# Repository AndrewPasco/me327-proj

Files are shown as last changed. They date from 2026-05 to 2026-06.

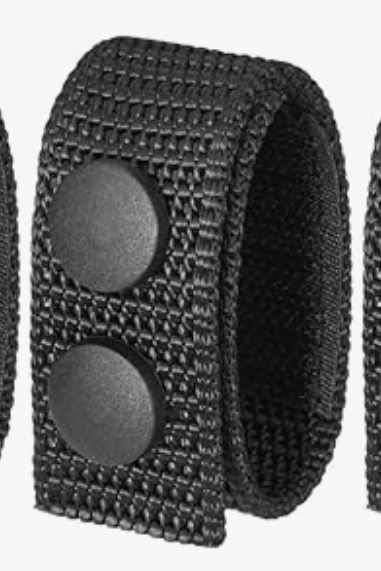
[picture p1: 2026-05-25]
media/belt-keeper.png

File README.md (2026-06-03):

# ME327 Haptic Belt: Covert Early Warning Communication System

> **ME327: Design and Control of Haptic Systems — Team 14**  
> Joseph Heimerl · Andrew Pasco · Ashlynn Sweet · Brody Todd

A wearable haptic belt that translates aerial threat detections (e.g., UAV positions) into real-time directional tactile cues. Eight coin-style ERM vibration motors spaced around the waist give the operator a passive, silent, always-on awareness of threats in their environment.

---

## How It Works

1. A **host computer** (running a threat-detection or simulation pipeline) detects a threat and encodes its position as `(x, y, z)` coordinates in a local frame.
2. The host sends a BLE packet to the belt controller (Particle Argon).
3. The **BNO085 IMU** continuously provides the operator's orientation as a quaternion.
4. The firmware computes the **relative bearing** from the operator to the threat, selects the nearest motor(s), and drives them at an intensity inversely proportional to threat range.
5. The belt simultaneously streams the current orientation quaternion back to the host for visualization.

As the operator turns, the vibration pattern rotates with them — always pointing toward the threat in the operator's frame.

---

## Repository Structure

```
me327-proj/
├── Analysis/                          # Vibration analysis
│   └── Analysis.m                     # MATLAB 2-DOF housing vibration model
├── CAD/                               # 3D-printed housing and belt buckle STL files
├── belt_controller/                   # Earlier prototype firmware (reference)
├── controllerTest/                    # Firmware + host BLE utilities
│   ├── controllerTest/                # Particle Workbench project
│   │   ├── src/                       # All firmware source
│   │   │   ├── controllerTest.cpp     # Entry point (setup / loop)
│   │   │   ├── HapticBelt.h/.cpp      # Top-level orchestrator
│   │   │   ├── BeltBLE.h/.cpp         # BLE peripheral (Rx threats / Tx orientation)
│   │   │   ├── BeltIMU.h/.cpp         # IMU interface + quaternion math
│   │   │   ├── ThreatTracker.h/.cpp   # Threat state machine (parse + store)
│   │   │   ├── HapticSignature.h      # Temporal vibration patterns per threat
│   │   │   └── MotorDriver.h/.cpp     # PWM abstraction for 8 ERM motors
│   │   ├── lib/                       # Vendored libraries
│   │   │   ├── Adafruit_BNO08x_Sahagun/
│   │   │   ├── Adafruit_BusIO_Sahagun/
│   │   │   └── Adafruit_Unified_Sensor_Sahagun/
│   │   └── project.properties         # Particle project config + dependencies
│   ├── bleakListener.py               # Host: receive orientation from belt (debug)
│   ├── bleakScanAndListen             # Host: scan + connect by device name
│   ├── bleakScanner                   # Host: passive BLE scanner
│   └── serialListener.py              # Host: USB Serial monitor
├── docs/                              # Design notes and project documentation checkpoints
├── media/                             # Visual assets for the project documentation
├── v_env/                             # Host-side GUI & threat simulation scripts
│   ├── brody_sim_main.py              # Main demo simulation (waves + spiral threats)
│   ├── gui_ashlynn_sim.py             # Game-mode simulation (4 escalating waves)
│   ├── gui_update_on_event.py         # Interactive debug / intro GUI (click-to-place)
│   ├── gui_drag_and_drop.py           # Drag-and-drop threat placement
│   ├── gui_single.py                  # Single-threat GUI
│   ├── gui_mult.py                    # Multi-threat GUI
│   ├── gui_varforce.py                # Variable-force multi-threat GUI
│   ├── gui_update_continously.py      # Continuous-update visualization
│   ├── update_on_event_brody_simulation.py      # BLE simulation + mouse test
│   ├── update_on_event_brody_simulation_TEST.py # Test variant of above
│   ├── pyproject.toml                 # Python project configuration
│   └── uv.lock                        # Lockfile for Python dependencies
├── architecture.md                    # Detailed design and architecture document
├── LICENSE                            # MIT License
└── README.md                          # This file
```

---

## Hardware

| Component | Part | Notes |
| :--- | :--- | :--- |
| Microcontroller | Particle Argon (nRF52840) | BLE, I2C, 12 PWM pins |
| IMU | BNO085 (I2C) | Game Rotation Vector report @ ~100 Hz |
| Motor Drivers | DRV8833 ×4 | 2 motors per driver, PWM control |
| Actuators | 8× coin ERM vibration motors | Equally spaced around waist |
| Structure | Elastic belt + 3D-printed clamshell housings | Rigid skin contact |

### Pin Mapping (Particle Argon)

| Resource | Pins |
| :--- | :--- |
| IMU (I2C) | SDA / SCL (default bus) |
| Motor 0 (forward) | D5 |
| Motor 1 | A5 |
| Motor 2 | A4 |
| Motor 3 | A2 |
| Motor 4 | A1 |
| Motor 5 | D6 |
| Motor 6 | D8 |
| Motor 7 | D4 |
| Status LED | D7 (onboard) |

---

## Firmware

### Building & Flashing

The firmware is a [Particle Workbench](https://docs.particle.io/tools/developer-tools/workbench/) project.

1. Open `controllerTest/controllerTest/` in VS Code with the Particle Workbench extension installed.
2. Select your target device (Argon) and Device OS version.
3. Run **Particle: Flash application (local)** or use the Particle CLI:

```bash
particle flash --usb controllerTest
```

### Software Modules

See [`architecture.md`](architecture.md) for the full design document. In brief:

| Module | Class | Purpose |
|:---|:---|:---|
| Orchestrator | `HapticBelt` | Ties all subsystems together; owns the main `loop()` |
| BLE | `BeltBLE` | GATT peripheral; Rx threat packets, Tx orientation quaternion |
| IMU | `BeltIMU` | BNO085 driver; quaternion re-orientation, reset recovery |
| Threat State | `ThreatTracker` | Parses BLE packets; maintains up to 10 active threats |
| Haptic Signatures | `HapticSignature` | Temporal vibration patterns (on/off timing) per threat for tactile differentiation |
| Motors | `MotorDriver` | PWM abstraction for 8 ERMs at 500 Hz |

### BLE Protocol

The belt advertises as **`"Argon Test"`** over BLE with service UUID `62c3cf89-247b-4c0f-a70d-651080844609`.

**Host → Belt (Rx characteristic `...844609`)**

Semicolon-separated threat packets, UTF-8 encoded:
```
"<id>,<x>,<y>,<z>[;<id>,<x>,<y>,<z>;...]"
```
- `id`: integer threat identifier (0–9; each slot has a unique haptic signature)
- `x`, `y`: position in the host's local frame (meters or arbitrary units; `+x` = right, `+y` = forward)
- `z`: depth / altitude — set to `-1` to **remove** a threat

**Belt → Host (Tx characteristic `...844608`)**

Orientation quaternion, sent as a comma-separated string each loop:
```
"<w>,<x>,<y>,<z>"
```

---

## Host-Side Python Tools

### BLE Debug Utilities

Located in `controllerTest/`. Dependencies managed with `uv`.

```bash
# Install dependencies
cd controllerTest
uv add bleak

# Listen for orientation packets from the belt
uv run bleakListener.py

# Scan for the belt and listen
uv run bleakScanAndListen

# USB Serial monitor (no BLE required)
uv run serialListener.py
```

> **Device MAC address** is printed over USB Serial at boot:  
> `BLE MAC: XX:XX:XX:XX:XX:XX`  
> Update `DEVICE_MAC` in the Python scripts accordingly.

### Simulation & GUI

Located in `v_env/`. Requires `pygame` and `bleak`.

| Script | Purpose |
| :--- | :--- |
| `brody_sim_main.py` | **Main demo simulation.** Spiral threats approach across escalating waves; merges Ashlynn's wave logic with Brody's UI. Used during the live demo. |
| `gui_update_on_event.py` | **Interactive debug / intro tool.** Click to place threats, drag to reposition, right-click to remove. Sector wheel visualization shows motor mapping. Good for introducing a user to the system. |
| `gui_ashlynn_sim.py` | Game-mode simulation with 4 escalating waves and lock-on neutralization mechanic. |
| `gui_drag_and_drop.py` | Simple drag-and-drop threat placement GUI. |
| `gui_single.py` | Single-threat GUI with BLE. |
| `gui_mult.py` | Multi-threat GUI with BLE. |
| `gui_varforce.py` | Multi-threat with variable force GUI. |
| `gui_update_continously.py` | Continuous-update threat visualization with sector wheel. |

All simulation scripts connect to the belt automatically by scanning for a device named `"Argon"`.

**Controls (simulation scripts):**
- `SPACE` — start / restart simulation
- `← →` arrow keys — rotate heading manually (when BLE is not connected)

---

## IMU Orientation Notes

The BNO085 reports orientation relative to its default flat-mount frame. The firmware corrects for the physical mounting orientation of the board on the belt via a configurable initial quaternion passed to `BeltIMU::setup()`:

```cpp
// HapticBelt.cpp — adjust to match your board mounting angle
Quat initialOrientation{sqrt(2)/2, 0, sqrt(2)/2, 0};
IMUHandler.setup(initialOrientation);
```

To find the right quaternion for a new mounting orientation:
1. Orient the belt as you want "forward" to be.
2. Read the raw quaternion over Serial.
3. Pass that quaternion as `initialOrientation`.

The IMU module also handles sensor resets transparently: it computes a continuity-preserving offset quaternion so the heading does not jump when the BNO085 resets mid-session.

---

## Haptic Rendering

Motor index 0 corresponds to "forward" (front of the belt). Motors are numbered 0–7 clockwise when viewed from above.

For each active threat:
1. Compute target azimuth: `-(atan2(y, x) × 180/π − 90°)` — converts from standard math to compass convention (0° = forward, clockwise positive)
2. Subtract current yaw to get relative bearing, normalized to (−180°, +180°]
3. Map bearing to nearest motor index (45° sectors)
4. Scale intensity: `intensity = clamp(1 − range/400, 0.1, 1.0)`

Each threat slot (0–9) is assigned a unique **haptic signature** — a temporal on/off vibration pattern defined in `HapticSignature`. This allows the operator to distinguish between multiple simultaneous threats by feel. The motor only fires when the threat's signature is in its "active" phase.

---

## Analysis & Simulation

We also model the mechanical dynamics of the belt for design optimization:

**`Analysis/Analysis.m`** (MATLAB) — 2-DOF mass-spring-damper model comparing vibration response of an unconstrained belt vs. a belt worn on a person. Models ERM forcing and housing dynamics.

---

## License

MIT License
ME327 Academic Project, Stanford University, Spring 2026.

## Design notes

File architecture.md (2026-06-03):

## ME327 Haptic Belt — Requirements and Code Architecture

This document describes the requirements for the haptic belt firmware and the implemented code architecture.

---

### Requirements

1. Receive incoming local-frame threat detections (as if detected by a device worn by the operator) via BLE from the host computer.
   - Determine the relative threat vector. Based on the relative threat vector, determine which motor(s) should be activated and their associated duty cycles.
   - Update the relative threat vector as the operator moves / yaws.
2. Process incoming data from the BNO085 IMU.
   - Calibrate belt mounting orientation at startup (configurable initial quaternion).
   - Maintain continuous orientation estimate; recover gracefully from IMU resets.
3. Stream the current orientation quaternion back to the host computer for rendering / visualization.
4. Manage PWM signals to 8 ERM vibration motors based on detected threats.

---

### Relevant System Details

**Microcontroller:** Particle Argon (Nordic Semiconductor nRF52840 SoC)
- ARM Cortex-M4F @ 64 MHz, 1 MB flash, 256 KB RAM
- Bluetooth LE central and peripheral support
- 20 mixed-signal GPIO (6× Analog, 8× PWM), UART, I2C, SPI
- Hardware FPU; DSP instructions; AES encryption accelerator
- 12 PWM-compatible pins, organized in three groups of four (same frequency per group; independent duty cycles)

**IMU:** BNO085 (I2C, via Adafruit_BNO08x library, Sahagun fork)
- Reports used: `SH2_GAME_ROTATION_VECTOR` (absolute orientation quaternion)
- Quaternion re-orientation applied at startup; offset correction applied after any sensor reset

**Motor Drivers:** DRV8833 ×4, controlled via PWM

---

### Implemented Architecture

#### 1. Coordinate Frames

| Frame | Description |
| :--- | :--- |
| **Global Frame (G)** | Fixed to the world. Threat positions are expressed here (x, y, z coordinates received from host). |
| **Body Frame (B)** | The current orientation of the belt/user. |
| **Initial/Reference Orientation** | A configurable quaternion passed to `BeltIMU::setup()` representing where the IMU is considered "forward" relative to its flat-mount default. Currently set to `{√2/2, 0, √2/2, 0}` to account for board mounting angle. |

#### 2. Class Hierarchy & Responsibilities

```
HapticBelt          (top-level orchestrator)
├── BeltBLE         (BLE peripheral: Rx threat data, Tx orientation)
├── BeltIMU         (I2C IMU interface: quaternion + heading)
├── ThreatTracker   (parses BLE packets, maintains threat state)
│   └── HapticSignature  (temporal vibration pattern per threat)
└── MotorDriver     (PWM abstraction for 8 ERM motors)
```

| Class | File(s) | Responsibility |
| :--- | :--- | :--- |
| **HapticBelt** | `HapticBelt.h/.cpp` | Top-level orchestrator. Owns all subsystems. Calls `setup()` and `loop()`. Pulls quaternion from `BeltIMU`, converts to yaw, queries active threats from `ThreatTracker`, maps threats to motors, and transmits orientation back over BLE via `BeltBLE`. |
| **BeltBLE** | `BeltBLE.h/.cpp` | Manages the BLE peripheral. Registers custom GATT service with Rx (write-without-response) and Tx (notify) characteristics. Passes a callback+context to the Rx characteristic on setup. Provides `transmit_orientation(w,x,y,z)` to broadcast the current quaternion. |
| **BeltIMU** | `BeltIMU.h/.cpp` | Interfaces with the BNO085 via I2C. Applies an initial re-orientation quaternion at startup. Handles IMU resets by computing a continuity-preserving offset quaternion. Exposes `get_quaternion()` (relative to initial orientation) and `get_heading()` (yaw in degrees). |
| **ThreatTracker** | `ThreatTracker.h/.cpp` | Holds a fixed-size array of up to 10 `Threat` structs. Provides a static `rx_callback` (passed to `BeltBLE::setup`) that stores incoming BLE bytes behind a `Mutex`. `update()` parses the buffered string and adds/updates/removes threats. `getActiveThreats()` returns pointers to currently active threats. Each threat slot is pre-assigned a unique `HapticSignature` at construction. |
| **HapticSignature** | `HapticSignature.h` | Defines a temporal on/off vibration pattern via an array of switch times (milliseconds). `is_active()` returns whether the motor should fire at the current time, cycling through the pattern. A zero-length signature is always on. Up to 10 entries per pattern (`MAX_SIGNATURE_LENGTH = 10`). |
| **MotorDriver** | `MotorDriver.h/.cpp` | Abstracts PWM control for 8 motors at 500 Hz. Maps motor index 0–7 to Argon pins `{D5, A5, A4, A2, A1, D6, D8, D4}`. `triggerMotor(index, intensity)` writes a 0–255 PWM value; `stopAllMotors()` zeroes all channels. |

#### 3. Key Data Structures

```cpp
// BeltIMU.h
struct Quat {
    float w, x, y, z;
};
// Utility functions (free functions in BeltIMU.cpp):
Quat Qmultiply(const Quat& a, const Quat& b); // Hamilton product + normalize
Quat Qconj(const Quat& q);                     // Quaternion conjugate
Quat Qnormalize(Quat q);                        // Unit normalization
void printQuat(Quat q);                          // Serial debug print

// HapticSignature.h
class HapticSignature {
    unsigned long switchTimes[MAX_SIGNATURE_LENGTH]; // on/off durations (ms)
    size_t length;                                   // 0 = always on
    bool is_active();  // returns current on/off state, cycling through pattern
};

// ThreatTracker.h
struct Threat {
    int   id     = -1;
    bool  active = false;
    float coords[3] = {0, 0, 0};  // x, y, z in host coordinate frame
    HapticSignature signature;     // unique temporal vibration pattern
};
```

#### 4. Data Flow (Main Loop)

```
setup():
  BeltBLE::setup(ThreatTracker::rx_callback, &ThreatTrack)
    └─ registers Rx/Tx GATT characteristics; begins BLE advertising

  BeltIMU::setup({√2/2, 0, √2/2, 0})
    └─ begin_I2C(), enable SH2_GAME_ROTATION_VECTOR report, store initQ

  MotorDriver::setup()
    └─ configure 8 PWM pins @ 500 Hz, zero all outputs

loop() [runs continuously]:
  1. BeltIMU::check_connection()
        └─ reconnects if needed; computes offset quaternion after any IMU reset

  2. BeltIMU::get_quaternion()
        └─ reads SH2 rotation vector → applies re-orientation (Qmultiply(raw, Qconj(initQ)))
           → applies continuity offset → returns finalQuat

  3. Convert quaternion → yaw (degrees) via standard Euler decomposition:
        yaw = -atan2(2(w·z + x·y), 1 − 2(y² + z²)) × 180/π   // negated for compass convention

  4. ThreatTracker::update()
        └─ safely copies buffered byteString (Mutex-protected)
           → parses semicolon-separated "id,x,y,z" tokens
           → z == -1 ⟹ deactivate; otherwise add/update threat

  5. HapticBelt::renderHaptics(yaw)
        a. getActiveThreats() → list of active Threat*
        b. For each threat:
             targetAzimuth = -(atan2(y, x) × 180/π − 90°)  // compass convention
             error = targetAzimuth − yaw                     // relative bearing
             error normalized to (−180, +180]
             motorIndex = round(normalizeAngle(error) / 45°) mod 8
             range = √(x² + y²)
             intensity = clamp(1 − range/400, 0.1, 1.0)
             if threat.signature.is_active():                // haptic signature gating
                 MotorDriver::triggerMotor(motorIndex, intensity)

  6. BeltBLE::transmit_orientation(w, x, y, z)
        └─ formats as "w,x,y,z" string → Tx NOTIFY characteristic
```

#### 5. BLE Protocol

| Direction | UUID | Format | Description |
| :--- | :--- | :--- | :--- |
| Host → Belt (Rx) | `...844609` | `"id,x,y,z[;id,x,y,z...]"` | Semicolon-separated threat packets. `z == -1` signals threat removal. |
| Belt → Host (Tx) | `...844608` | `"w,x,y,z"` | Current orientation quaternion, 2 decimal places, sent each loop. |

#### 6. Hardware Pin Mapping (Particle Argon)

| Resource | Pin(s) | Notes |
| :--- | :--- | :--- |
| **IMU (I2C)** | SDA / SCL (default I2C bus) | BNO085 via `Adafruit_BNO08x` |
| **Motor 0 (forward)** | D5 | DRV8833 PWM input |
| **Motor 1** | A5 | DRV8833 PWM input |
| **Motor 2** | A4 | DRV8833 PWM input |
| **Motor 3** | A2 | DRV8833 PWM input |
| **Motor 4** | A1 | DRV8833 PWM input |
| **Motor 5** | D6 | DRV8833 PWM input |
| **Motor 6** | D8 | DRV8833 PWM input |
| **Motor 7** | D4 | DRV8833 PWM input |
| **Status LED** | D7 (onboard) | Blink each loop iteration |
| **PWM Frequency** | 500 Hz | Set via `analogWrite(pin, 0, 500)` in `MotorDriver::setup()` |

---

### Third-Party Dependencies

| Library | Version | Purpose |
| :--- | :--- | :--- |
| `Adafruit_BNO08x_Sahagun` | 1.2.6 | BNO085 I2C driver (forked for Particle compatibility) |
| `Adafruit_BusIO_Sahagun` | — | I2C/SPI bus abstraction (transitive dep) |
| `Adafruit_Unified_Sensor_Sahagun` | — | Unified sensor abstraction (transitive dep) |

Dependencies are declared in `controllerTest/project.properties` and bundled under `controllerTest/lib/`.

---

### Host-Side Tooling (Python)

#### BLE Debug Utilities

Located in `controllerTest/`:

| Script | Purpose |
| :--- | :--- |
| `bleakListener.py` | Connects to the Argon by MAC address, subscribes to the Tx characteristic (orientation), and prints received packets to stdout. Development/debug tool. |
| `bleakScanAndListen` | Scans for the Argon by device name (`"Argon Test"`) before connecting. |
| `bleakScanner` | Passive BLE scanner utility. |
| `serialListener.py` | Reads USB Serial output from the Argon for local debug without BLE. |

Dependencies managed with `uv`. Run with `uv run <script>` after adding `bleak` via `uv add bleak`.

#### Simulation & GUI

Located in `v_env/`. Requires `pygame` and `bleak`.

| Script | Purpose |
| :--- | :--- |
| `brody_sim_main.py` | **Main demo simulation.** Spiral threats approach across escalating waves; merges Ashlynn's wave logic with Brody's UI. Used during the live demo. |
| `gui_update_on_event.py` | **Interactive debug / intro tool.** Click to place threats, drag to reposition, right-click to remove. Sector wheel visualization shows motor mapping in real time. |
| `gui_ashlynn_sim.py` | Game-mode simulation with 4 escalating waves and lock-on neutralization mechanic. |
| `gui_drag_and_drop.py` | Simple drag-and-drop threat placement GUI. |
| `gui_single.py` | Single-threat GUI with BLE. |
| `gui_mult.py` | Multi-threat GUI with BLE. |
| `gui_varforce.py` | Multi-threat with variable force GUI. |
| `gui_update_continously.py` | Continuous-update threat visualization with sector wheel. |

All simulation scripts auto-connect to the belt by scanning for a device named `"Argon"`. Controls: `SPACE` to start/restart, `← →` arrow keys to rotate heading manually (when BLE is not connected).

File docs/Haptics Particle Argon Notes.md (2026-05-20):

# BLE stuff
look at ppcp for improving transfer rates

Making services:
```cpp
// PROTOTYPE 
BleUuid(const String& uuid); 
BleUuid(const char* uuid);
// EXAMPLE 
BleUuid myCustomService("240d5183-819a-4627-9ca9-1aa24df29f18");
```

Giving Services characteristics
- no separate class for the characteristic, a characteristic is determined buy a uuid as well
```cpp
// global variables
BleUuid myCustomCharacteristicUuid("240d5183-819a-4627-9ca9-1aa24df29f18");

//example implementation
BleCharacteristic customChar("temp",
 							BleCharacteristicProperty::NOTIFY, //see below
 							myCustomCharacteristicUuid, 
 							myCustomService);

// then I think you need to add the characteristic
// in setup
setup() {
	BLE.addCharacteristic(customChar);
}
```

Appending services to the advertisement:
```cpp
// in setup:
BleAdvertisingData advData;
advData.appendServiceUUID(myCustomService);

BLE.setDeviceName("Argon Test");
BLE.advertise();
```

Different Characteristic Properties:
> [!info]+ BLE Characteristic Properties:
> - `BleCharacteristicProperty::BROADCAST` (0x01) The value can be broadcast.
>- `BleCharacteristicProperty::READ` (0x02) The value can be read.
> - `BleCharacteristicProperty::WRITE_WO_RSP` (0x04) The value can be written without acknowledgement. For example, the UART peripheral example uses this characteristic properly to receive UART data from the central device.
> - `BleCharacteristicProperty::WRITE` (0x08) The value can be written to the peripheral from the central device.
> - `BleCharacteristicProperty::NOTIFY` (0x10) The value is published by the peripheral without acknowledgement. This is the standard way peripherals periodically publish data.
> - `BleCharacteristicProperty::INDICATE` (0x20) The value can be indicated, basically publish with acknowledgement.
> - `BleCharacteristicProperty::AUTH_SIGN_WRITES` (0x40) The value supports signed writes. This is operation not supported.
> - `BleCharacteristicProperty::EXTENDED_PROP` (0x80) The value supports extended properties. This operation is not supported.

characteristics can have one or more values

How to actually do stuff with characteristics:
BLE characteristic w/ data recieved:

```cpp
// Global variable 
BleCharacteristic(	const char* desc, 
					BleCharacteristicProperty properties, 
					BleUuid charUuid, 
					BleUuid svcUuid, 
					BleOnDataReceivedCallback callback = nullptr, 
					void* context = nullptr) // context is extra info sent to 
											// callback (typically "this" if an 
											// object)

BleCharacteristic rxCharacteristic("rx",
 								  	BleCharacteristicProperty::WRITE_WO_RSP,
 								  	rxUuid, 
 								  	serviceUuid, 
 								  	onDataReceived, 
 								  	NULL);
 								  	
// The onDataRecieved is a callback function:
void onDataReceived(const uint8_t* data, 
					size_t len, 
					const BlePeerDevice& peer, 
					void* context)

// in setup, need to register characteristic (if a peripheral)
setup() {
	BLE.addCharacteristic(customChar);
	
	// can also tie the callback here
	myCharacteristic.onDataReceived(onDataReceived, NULL);
}
```

The `onDataReceived()` handler is run from the BLE thread. You should avoid lengthy or blocking operations since it will affect other BLE processing. Additionally, the BLE thread has a smaller stack than the main application (loop) thread, so you avoid functions that require a large amount of stack space. To prevent these issues, you should set a flag in the data received handler and perform lengthy or stack-intensive operations from the `loop()` instead. For example, you should not call `Particle.publish()`, `WiFi.clearCredentials()`, and many other functions directly from the onDataReceived handler.

To write data to a characteristic:
```cpp
// PROTOTYPE template
<typename T> 
ssize_t setValue(T val) const; 
// EXAMPLE 
uint16_t value = 0x1234; 
characteristic.setValue(value);
```
this apparently works with arbitrary data types including structs somehow I will have to test how that works

Because the onDataReceived is run on another thread, might have to do thread safety stuff
Log.info() is thread safe, serial is not

need to use a recursive mutex if one thread will be locking 

mutex example
```cpp
// globally
Mutex coordsMutex;

// in a funciton
WITH_LOCK(coordsMutex) {  
	localX = x;  
	localY = y;  
	localZ = z;  
}
```

## useful data transmission functions:
sscanf "string scan formatted"
parses formatted data from c string
<span style="color:rgb(192, 0, 0)">note c strings must end in a 0 byte</span> `'\0'`

address operator:
sscanf needs pointers to variables so it can write results.  
  
Correct:  
&x  
  
Incorrect:  
x
```cpp
int sscanf(const char* str, const char* format, ...); //returns number of successfully matched values 

char text[] = "1.23,4.56,7.89";

float x,y,z;
int matched = sscanf(  
	text,  
	"%f,%f,%f",  
	&x,  
	&y,  
	&z  
);
```

note:
uint8_t is exactly 1 byte of memory (8 bits per byte)
note the data arg for callback is: `const uint8_t* data`
- stores an array of bytes essentially

```cpp
void onDataReceived(const uint8_t* data, 
					size_t len, 
					const BlePeerDevice& peer, 
					void* context)
{
	// buffer to hold text  
	char buffer[64];  
	  
	// avoid overflowing the buffer  
	size_t copyLen = min(len, sizeof(buffer) - 1);  
	  
	// copy raw BLE bytes into char buffer  
	memcpy(buffer, data, copyLen);  
	  
	// add null terminator  
	buffer[copyLen] = '\0';  
	  
	// now buffer is a valid C string
}

```

the context actually must be casted into the correct pointer type for the class context you want:
```cpp
void onDataReceived(const uint8_t* data, 
					size_t len, 
					const BlePeerDevice& peer, 
					void* context)
{
MyClass* self = (MyClass*)context;
}
```

here is some function passing sematic stuff:
```cpp
class MainClass 
{
private:   
	 BleHandler ble;    
	 CallbackClass callbackClass;
 public:    
	 void setup() {        
	 	ble.setup(CallbackClass::onCallback, &callbackClass);    
	 }
 };
```

```cpp
class BleHandler {  
private:  
	BleCharacteristic rx;  
  
public:  
	void setup(BleOnDataReceivedCallback callback, void* context) {  
		rx.onDataReceived(callback, context);  
	}  
};
```

```cpp
class CallbackClass {  
public:  
	static void onCallback(const uint8_t* data,  
						   size_t len,  
						   const BlePeerDevice& peer,  
						   void* context)  
	{  
		CallbackClass* self = static_cast<CallbackClass*>(context);  
		self->handleData(data, len, peer);  
	}  

private:  
	void handleData(const uint8_t* data,  
					size_t len,  
					const BlePeerDevice& peer)  
	{  
	// can access private members here  
	}
};
```

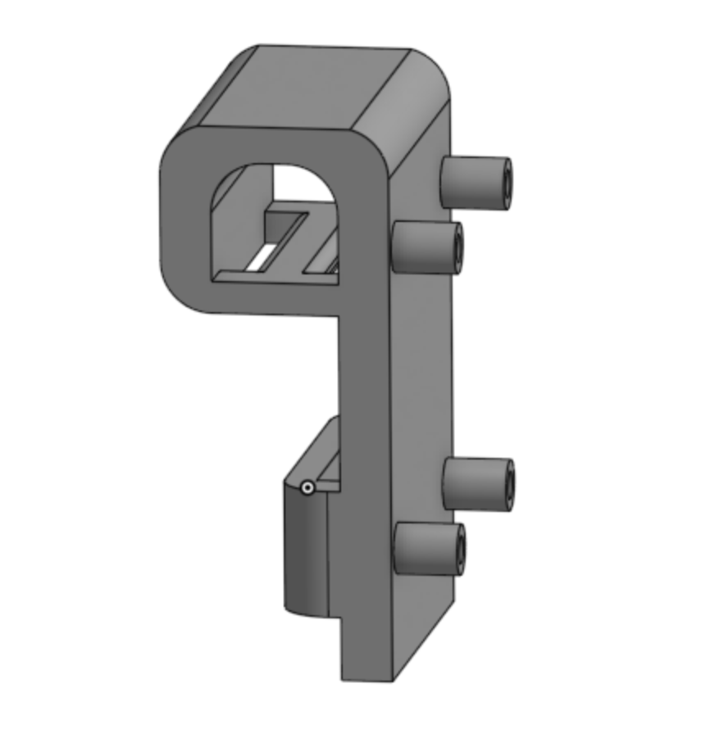
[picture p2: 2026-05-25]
media/327-buckle.png

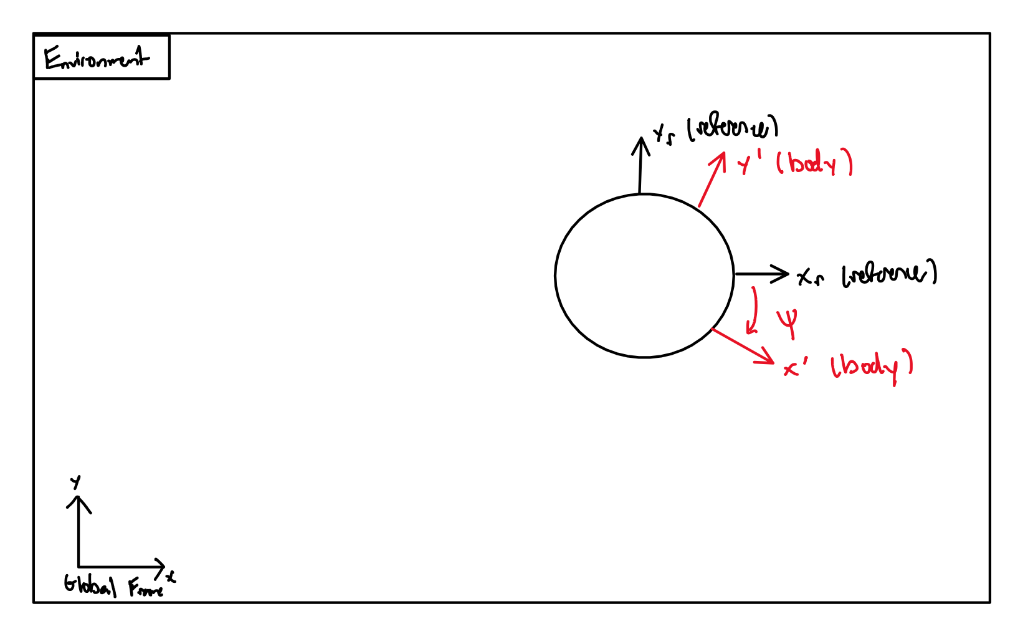
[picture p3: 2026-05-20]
media/frames-checkpoint1.png

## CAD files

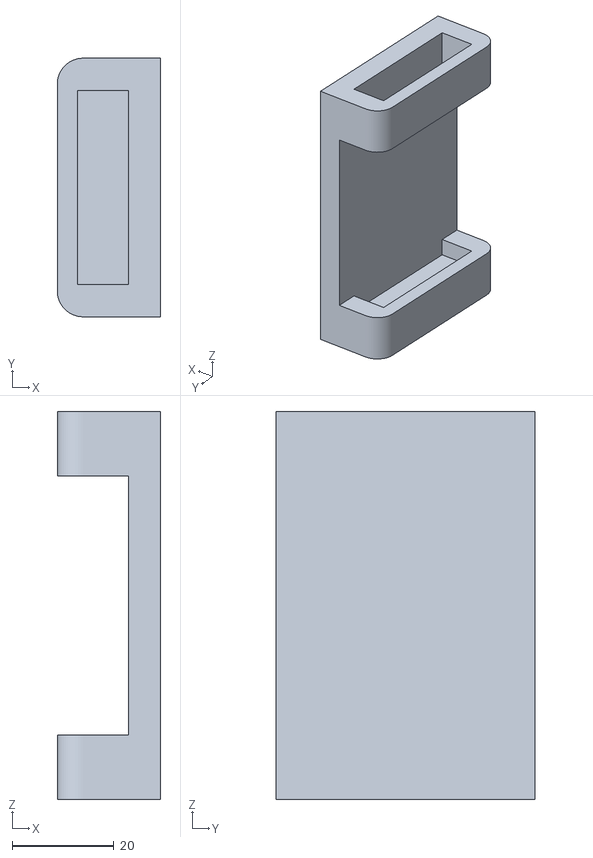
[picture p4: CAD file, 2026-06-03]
CAD/group14-2026-base-no-driver.stl
20.3 x 50.8 x 76.2

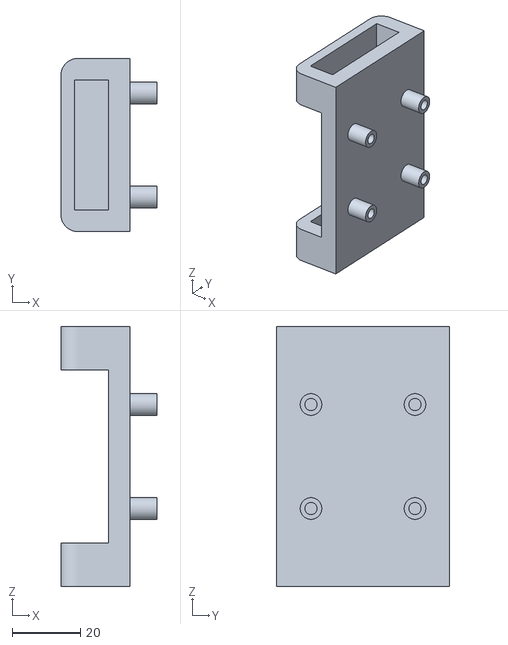
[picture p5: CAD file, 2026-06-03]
CAD/group14-2026-base-driver.stl
28.3 x 50.8 x 76.2

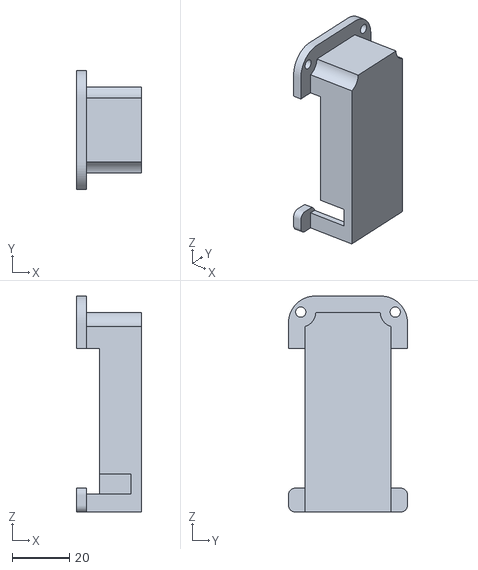
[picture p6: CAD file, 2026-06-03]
CAD/group14-2026-cover-argon.stl
22.6 x 41.6 x 75.5

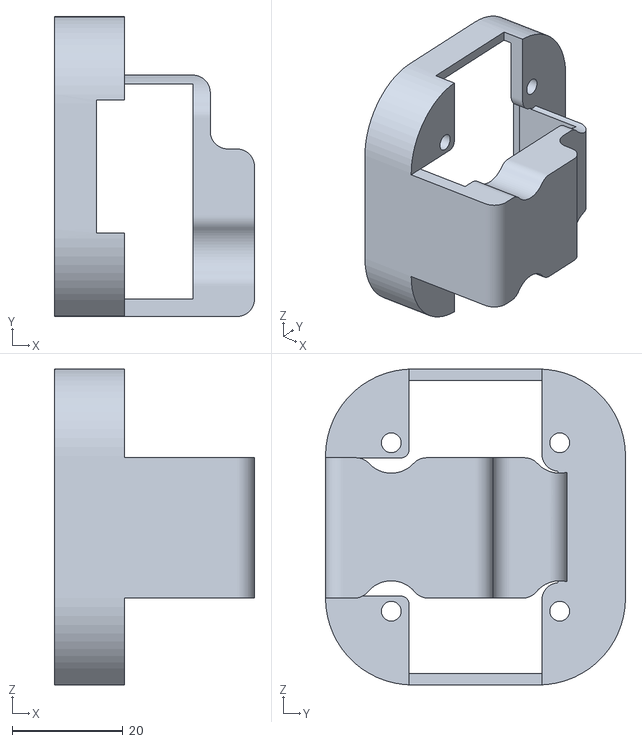
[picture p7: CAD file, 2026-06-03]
CAD/group14-2026-cover-driver.stl
36.2 x 54.3 x 57.1

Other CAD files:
CAD/group14-2026-base-argon.stl

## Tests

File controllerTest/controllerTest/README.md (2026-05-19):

# controllerTest

This firmware project was created using [Particle Developer Tools](https://www.particle.io/developer-tools/) and is compatible with all [Particle Devices](https://www.particle.io/devices/).

Feel free to replace this README.md file with your own content, or keep it for reference.

## Table of Contents
- [Introduction](#introduction)
- [Prerequisites To Use This Template](#prerequisites-to-use-this-repository)
- [Getting Started](#getting-started)
- [Particle Firmware At A Glance](#particle-firmware-at-a-glance)
  - [Logging](#logging)
  - [Setup and Loop](#setup-and-loop)
  - [Delays and Timing](#delays-and-timing)
  - [Testing and Debugging](#testing-and-debugging)
  - [GitHub Actions (CI/CD)](#github-actions-cicd)
  - [OTA](#ota)
  - [Assets](#assets)
  - [Environment](#environment)
- [Support and Feedback](#support-and-feedback)
- [Version](#version)

## Introduction

For an in-depth understanding of this project template, please refer to our [documentation](https://docs.particle.io/firmware/best-practices/firmware-template/).

## Prerequisites To Use This Repository

To use this software/firmware on a device, you'll need:

- A [Particle Device](https://www.particle.io/devices/).
- Windows/Mac/Linux for building the software and flashing it to a device.
- [Particle Development Tools](https://docs.particle.io/getting-started/developer-tools/developer-tools/) installed and set up on your computer.
- Optionally, a nice cup of tea (and perhaps a biscuit).

## Getting Started

1. While not essential, we recommend running the [device setup process](https://setup.particle.io/) on your Particle device first. This ensures your device's firmware is up-to-date and you have a solid baseline to start from.

2. If you haven't already, open this project in Visual Studio Code (File -> Open Folder). Then [compile and flash](https://docs.particle.io/getting-started/developer-tools/workbench/#cloud-build-and-flash) your device. Ensure your device's USB port is connected to your computer.

3. Verify the device's operation by monitoring its logging output:
    - In Visual Studio Code with the Particle Plugin, open the [command palette](https://docs.particle.io/getting-started/developer-tools/workbench/#particle-commands) and choose "Particle: Serial Monitor".
    - Or, using the Particle CLI, execute:
    ```
    particle serial monitor --follow
    ```

4. Uncomment the code at the bottom of the cpp file in your src directory to publish to the Particle Cloud! Login to console.particle.io to view your devices events in real time.

5. Customize this project! For firmware details, see [Particle firmware](https://docs.particle.io/reference/device-os/api/introduction/getting-started/). For information on the project's directory structure, visit [this link](https://docs.particle.io/firmware/best-practices/firmware-template/#project-overview).

## Particle Firmware At A Glance

### Logging

The firmware includes a [logging library](https://docs.particle.io/reference/device-os/api/logging/logger-class/). You can display messages at different levels and filter them:

```
Log.trace("This is trace message");
Log.info("This is info message");
Log.warn("This is warn message");
Log.error("This is error message");
```

### Setup and Loop

Particle projects originate from the Wiring/Processing framework, which is based on C++. Typically, one-time setup functions are placed in `setup()`, and the main application runs from the `loop()` function.

For advanced scenarios, explore our [threading support](https://docs.particle.io/firmware/software-design/threading-explainer/).

### Delays and Timing

By default, the setup() and loop() functions are blocking whilst they run, meaning that if you put in a delay, your entire application will wait for that delay to finish before anything else can run. 

For techniques that allow you to run multiple tasks in parallel without creating threads, checkout the code example [here](https://docs.particle.io/firmware/best-practices/firmware-template/).

(Note: Although using `delay()` isn't recommended for best practices, it's acceptable for testing.)

### Testing and Debugging

For firmware testing and debugging guidance, check [this documentation](https://docs.particle.io/troubleshooting/guides/build-tools-troubleshooting/debugging-firmware-builds/).

### GitHub Actions (CI/CD)

This project provides a YAML file for GitHub, automating firmware compilation whenever changes are pushed. More details on [Particle GitHub Actions](https://docs.particle.io/firmware/best-practices/github-actions/) are available.

### OTA

To learn how to utilize Particle's OTA service for device updates, consult [this documentation](https://docs.particle.io/getting-started/cloud/ota-updates/).

Test OTA with the 'Particle: Cloud Flash' command in Visual Studio Code or the CLI command 'particle flash'!

This firmware supports binary assets in OTA packages, allowing the inclusion of audio, images, configurations, and external microcontroller firmware. More details are [here](https://docs.particle.io/reference/device-os/api/asset-ota/asset-ota/).

### Assets

To include assets in your OTA bundle, create an `assets` folder in your project root and place your files there. These can include audio files, images, configuration files, or firmware for external microcontrollers.

To enable asset OTA, uncomment the following line in `project.properties`:
```
assetOtaDir=assets
```

See the [Asset OTA documentation](https://docs.particle.io/reference/device-os/api/asset-ota) for more details.

### Environment

To bundle environment variables with your firmware, create an `env.json` file in your project root. Uncomment the following line in `project.properties` to enable it:
```
env=env.json
```

See the [Environment documentation](https://docs.particle.io/reference/device-os/api/environment) for more details.

## Support and Feedback

For support or feedback on this template or any Particle products, please join our [community](https://community.particle.io)!

## Version

Template version 1.0.3

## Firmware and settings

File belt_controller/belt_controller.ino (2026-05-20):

#include "Particle.h"
#include "Adafruit_BNO08x_RVC.h"
#include "ThreatManager.h"

// --- System Configuration ---
// MANUAL mode: no WiFi/Cloud, BLE only: faster boot, lower power
SYSTEM_MODE(MANUAL);
// BLE callbacks run on a separate OS thread; shared state must be mutex-protected
SYSTEM_THREAD(ENABLED);

// Thread-safe logging (Serial.print is NOT safe with SYSTEM_THREAD)
SerialLogHandler logHandler(LOG_LEVEL_INFO);

// --- BLE Configuration ---
// Service UUID (unchanged from controllerTest for Python compatibility)
BleUuid beltServiceUuid("62c3cf89-247b-4c0f-a70d-651080844609");
// RX UUID:
BleUuid threatRxUuid("62c3cf89-247b-4c0f-a70d-651080844607");
// TX UUID (unchanged from controllerTest for Python compatibility)
BleUuid telemetryTxUuid("62c3cf89-247b-4c0f-a70d-651080844608");

// Forward-declare BLE callback
void onBleDataReceived(const uint8_t* data, size_t len,
    const BlePeerDevice& peer, void* context);

// TX: Belt → Host telemetry (NOTIFY)
BleCharacteristic telemetryChar("Telemetry",
    BleCharacteristicProperty::NOTIFY, telemetryTxUuid, beltServiceUuid);

// RX: Host → Belt threat messages (WRITE_WO_RSP)
BleCharacteristic threatRxChar("ThreatRx",
    BleCharacteristicProperty::WRITE_WO_RSP, threatRxUuid, beltServiceUuid,
    onBleDataReceived, NULL);

// --- BLE Thread-Safe Shared State ---
//
// DESIGN NOTE: We use global state here rather than the class-based callback
// pattern (MainClass → BleHandler → CallbackClass with void* context cast)
// documented in "Haptics Particle Argon Notes.md". Since
// belt_controller.ino is a flat .ino with no classes, the ring buffer and
// mutex are already in scope for the free-function callback — no context
// pointer needed (we pass NULL). If this grows to warrant encapsulation
// refactor by:
//   1. Wrapping the ring buffer + mutex in a class (e.g., ThreatReceiver)
//   2. Making onBleDataReceived a static member
//   3. Passing `this` as the void* context in the characteristic constructor
//   4. Casting context back to ThreatReceiver* inside the callback

/**
 * Binary message format for incoming threats over BLE.
 * 9 bytes, packed, little-endian.
 *
 * Python packing:  struct.pack('<Bff', id, bearing, range)
 *
 * Semantics:
 *   - New ID       → add to threat list
 *   - Existing ID  → update bearing/range
 *   - range == 0.0 → remove threat
 *
 * One message per BLE write. For multiple threats, the host sends
 * successive writes (handled on the Python side).
 */
struct __attribute__((packed)) ThreatMessage {
    uint8_t id;
    float bearing;
    float range;
};

// Ring buffer: BLE thread produces, loop() consumes
const int PENDING_BUFFER_SIZE = 8;
volatile int pendingWriteIdx = 0;
volatile int pendingReadIdx = 0;
ThreatMessage pendingThreats[PENDING_BUFFER_SIZE];
Mutex threatMutex;

// --- IMU ---
Adafruit_BNO08x_RVC rvc = Adafruit_BNO08x_RVC();

// --- Configuration ---
const unsigned long IMU_TIMEOUT_MS = 100; // Time before considering IMU disconnected
const unsigned long TELEMETRY_INTERVAL_MS = 100; // Interval for sending data back to host (Currently 10Hz)
const unsigned long THREAT_TIMEOUT_MS = 20000; // Time before a threat is considered stale (20s)
const int PWM_FREQUENCY = 500; // Maximum possible (also default)

// --- State Variables ---
float currentYawRaw = 0.0;
float referenceYaw = 0.0;
unsigned long lastImuUpdate = 0;
unsigned long lastTelemetrySend = 0;
bool imuConnected = false;

// --- Threat Manager ---
ThreatManager threatManager;

// --- Hardware Pins ---
// Map the 8 motors to specific pins on the Particle Argon
const int MOTOR_COUNT = 8;
const int motorPins[MOTOR_COUNT] = {
  A0, // Motor 0: Front (0 deg)
  A1, // Motor 1: Front-Right (45 deg)
  A2, // Motor 2: Right (90 deg)
  A3, // Motor 3: Back-Right (135 deg)
  D4, // Motor 4: Back (180 deg)
  D5, // Motor 5: Back-Left (225 deg)
  D6, // Motor 6: Left (270 deg)
  D8  // Motor 7: Front-Left (315 deg)
};

// =============================================================================
// BLE Callback (runs on BLE OS thread — keep minimal and non-blocking!)
// =============================================================================

/**
 * Called by the BLE stack when the host writes to the ThreatRx characteristic.
 * Copies the raw bytes into the ring buffer and returns immediately.
 * All parsing, threat management, and logging happens in loop().
 *
 * IMPORTANT: Do NOT call Serial.print, Particle.publish, or any blocking
 * function from this callback. Use Log.trace at most for lightweight debug.
 */
void onBleDataReceived(const uint8_t* data, size_t len,
    const BlePeerDevice& peer, void* context)
{
  // Validate message size — expect exactly one ThreatMessage per write
  if (len != sizeof(ThreatMessage)) return;

  WITH_LOCK(threatMutex) {
    int nextWrite = (pendingWriteIdx + 1) % PENDING_BUFFER_SIZE;
    if (nextWrite != pendingReadIdx) { // Buffer not full
      memcpy(&pendingThreats[pendingWriteIdx], data, sizeof(ThreatMessage));
      pendingWriteIdx = nextWrite;
    }
    // If buffer is full, silently drop (non-blocking, no allocation)
  }
}

// =============================================================================
// Motor Logic
// =============================================================================

/**
 * Triggers a specific motor with a given intensity.
 * @param motorIndex: 0-7
 * @param intensity: 0.0 (off) to 1.0 (max)
 */
void triggerMotor(int motorIndex, float intensity) {
  if (motorIndex < 0 || motorIndex >= MOTOR_COUNT) return;
  
  // Constrain intensity and map to 8-bit PWM (0-255)
  int pwmValue = (int)(constrain(intensity, 0.0, 1.0) * 255);
  
  analogWrite(motorPins[motorIndex], pwmValue);
}

/**
 * Sets all motor PWMs to 0.
 */
void stopAllMotors() {
  for (int i = 0; i < MOTOR_COUNT; i++) {
    analogWrite(motorPins[i], 0);
  }
}

// =============================================================================
// Telemetry
// =============================================================================

/**
 * Sends a telemetry update to the host over BLE (NOTIFY characteristic).
 * Format: "YAW,<heading>,IMU,<0|1>"
 *   - YAW: relative heading in degrees (float, 2 decimal places)
 *   - IMU: 1 if IMU is connected, 0 otherwise
 */
void sendTelemetry(float relativeYaw) {
  char buf[48];
  snprintf(buf, sizeof(buf), "YAW,%.2f,IMU,%d",
           relativeYaw, imuConnected ? 1 : 0);
  telemetryChar.setValue(buf);
  Log.trace("Telemetry -> %s", buf);
}

// =============================================================================
// Core Logic
// =============================================================================

// Normalizes an angle to the [0, 360) range
float normalizeAngle(float angle) {
  angle = fmod(angle, 360.0);
  if (angle < 0) {
    angle += 360.0;
  }
  return angle;
}

// Zeros the heading to the current physical orientation
void setReference() {
  referenceYaw = currentYawRaw;
  Log.info("Reference set to: %.2f", referenceYaw);
}

// Returns the heading relative to the set reference
float getHeading() {
  return normalizeAngle(currentYawRaw - referenceYaw);
}

/**
 * Drains the ring buffer of pending threat messages from BLE.
 * Called from loop() — safe to do heavy work here (logging, ThreatManager updates).
 */
void processPendingThreats() {
  WITH_LOCK(threatMutex) {
    while (pendingReadIdx != pendingWriteIdx) {
      ThreatMessage msg = pendingThreats[pendingReadIdx];
      pendingReadIdx = (pendingReadIdx + 1) % PENDING_BUFFER_SIZE;

      if (msg.range == 0.0f) {
        threatManager.removeThreat(msg.id);
        Log.info("Threat removed - ID: %d", msg.id);
      } else {
        threatManager.addOrUpdateThreat(msg.id, msg.bearing, msg.range);
        Log.info("Threat updated - ID: %d, Az: %.1f, Range: %.1f",
                 msg.id, msg.bearing, msg.range);
      }
    }
  }
}

// Haptic Renderer: determines motor activations based on active threats and current yaw
void renderHaptics() {
  float currentRelativeYaw = getHeading();
  
  // Clean up any old threats
  threatManager.cleanupStaleThreats(THREAT_TIMEOUT_MS);
  
  int activeCount = threatManager.getActiveThreatCount();
  if (activeCount == 0) {
    stopAllMotors();
    return;
  }
  
  Threat* activeThreats[MAX_THREATS];
  int count = threatManager.getActiveThreats(activeThreats, MAX_THREATS);

  // Stop all motors first, then trigger only the needed ones.
  stopAllMotors();
  
  float sectorSize = 360.0 / 8.0;

  for (int i = 0; i < count; i++) {
    float targetAzimuth = activeThreats[i]->bearing;
    float intensity = activeThreats[i]->range; // For now, use range as intensity or map inversely
    
    // Calculate shortest path error
    float error = targetAzimuth - currentRelativeYaw;
    // Normalize error to [-180, 180) to find the closest direction
    error = fmod(error + 540.0, 360.0) - 180.0; 

    // Shift by half a sector so the threshold is between motors
    int motorIndex = round(normalizeAngle(error) / sectorSize);
    if (motorIndex == 8) motorIndex = 0; // Wrap around

    triggerMotor(motorIndex, intensity);
  }
}

// =============================================================================
// Setup and Loop
// =============================================================================

void setup() {
  Serial.begin(115200);
  
  // Start hardware serial for BNO08x (Board RX to BNO085 SDA)
  Serial1.begin(115200); 

  Log.info("Haptic Belt - BLE + State Estimation Init");

  // --- IMU Init ---
  if (!rvc.begin(&Serial1)) { 
    Log.warn("Could not find BNO08x at startup!");
    // We don't block here. We let the loop handle reconnection/timeouts.
  } else {
    Log.info("BNO08x initialized.");
    imuConnected = true;
  }

  // --- Motor Init ---
  for (int i = 0; i < MOTOR_COUNT; i++) {
    pinMode(motorPins[i], OUTPUT);
  }

  // Set PWM Frequencies for the Argon groups
  // analogWrite(pin, value, frequency) sets frequency for the entire group
  analogWrite(motorPins[0], 0, PWM_FREQUENCY); // Sets frequency for Group A0-A3
  analogWrite(motorPins[4], 0, PWM_FREQUENCY); // Sets frequency for Group D4, D5, D6, D8

  stopAllMotors();

  // --- BLE Init ---
  // In MANUAL mode, we must explicitly enable BLE
  BLE.on();

  BLE.addCharacteristic(telemetryChar);
  BLE.addCharacteristic(threatRxChar);

  BleAdvertisingData advData;
  advData.appendServiceUUID(beltServiceUuid);
  BLE.setDeviceName("Argon Test"); // Keep existing name for now
  BLE.advertise(&advData);

  Log.info("BLE advertising started (Service: %s)", 
           beltServiceUuid.toString().c_str());
}

void loop() {
  unsigned long currentMillis = millis();

  // --- Process IMU Data (Non-blocking) ---
  BNO08x_RVC_Data headingData;
  if (rvc.read(&headingData)) {
    currentYawRaw = headingData.yaw;
    lastImuUpdate = currentMillis;
    if (!imuConnected) {
      Log.info("IMU Connection Recovered!");
      imuConnected = true;
    }
  }

  // --- Check IMU Health ---
  if (imuConnected && (currentMillis - lastImuUpdate > IMU_TIMEOUT_MS)) {
    Log.error("IMU Data Timeout! Lost connection.");
    imuConnected = false;
    stopAllMotors(); // Safety: stop haptics if we lose orientation
  }

  // --- Process incoming BLE threat messages ---
  processPendingThreats();

  // --- Serial debug commands (keep for development) ---
  if (Serial.available() > 0) {
    char cmd = Serial.read();
    if (cmd == 'c') { // Type 'c' in serial to calibrate/zero
      setReference();
    }
  }

  // --- Update Haptics based on state ---
  renderHaptics();

  // --- Send Telemetry ---
  if (currentMillis - lastTelemetrySend > TELEMETRY_INTERVAL_MS) {
    if (imuConnected) {
      sendTelemetry(getHeading());
    }
    lastTelemetrySend = currentMillis;
  }
}

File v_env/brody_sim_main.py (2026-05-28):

# Haptic belt threat simulation — main demo script
#
# Logic:  Ashlynn's simulation (spiral threats, wave schedule, shutdown cleanup)
# UI:     Brody's visualization (single forward cone, lock-on arc, decay mechanic)
#
# Controls:
#   SPACE          — start / restart
#   ← → arrow keys — rotate heading when BLE not connected
#
# BLE connects automatically to "Argon" device.
# Threat message format: spawn/move "id,x,y,0\n"  |  remove "id,x,y,-1\n"
#
# Runs on Python 3.11+ with: pygame, bleak

import pygame
import math
import asyncio
from bleak import BleakScanner, BleakClient
import threading
import random

# ─── CONFIG ──────────────────────────────────────────────────────────────────

WIDTH  = 800
HEIGHT = 800
FPS    = 30
CENTER = (WIDTH // 2, HEIGHT // 2)

METERS_TO_PX     = 300.0 / 500.0   # 500 m = 300 px (outer cone edge)
TERMINAL_M       = 50
TERMINAL_PX      = int(TERMINAL_M * METERS_TO_PX)   # 30 px

LOCK_ON_DURATION = 3.0              # seconds user must face sector to neutralize

NUM_MOTORS   = 8
SECTOR_SIZE  = 360.0 / NUM_MOTORS   # 45 °

SECTOR_INNER_RADIUS = 40
SECTOR_OUTER_RADIUS = 300

RANGE_RINGS_M = [100, 200, 300, 400, 500]

SPIRAL_OMEGA        = 0.2    # rad/s — angular drift rate for spiral threats
SPIRAL_RADIAL_SPEED = 10     # px/s  — inward speed for spiral threats

WAVE_CLEAR_DELAY = 3.0       # seconds between a wave being cleared and the next spawning

# Wave schedule (Ashlynn's).
# spawn_time: seconds after SPACE pressed. Wave 1 at T=3 gives a natural countdown.
# angle_deg: compass bearing FROM WHICH the threat approaches (0=N, 90=E, …).
WAVE_SCHEDULE = [
    {
        "spawn_time": 3.0,
        "label": "WAVE 1",
        "threats": [
            {"angle_deg":   0, "speed_mps": 10, "distance_m": 400},
            {"angle_deg": 175, "speed_mps": 10, "distance_m": 400},
        ],
    },
    {
        "spawn_time": 18.0,
        "label": "WAVE 2",
        "threats": [
            {"angle_deg":  45, "speed_mps": 12, "distance_m": 500},
            {"angle_deg": 225, "speed_mps": 12, "distance_m": 500},
        ],
    },
    {
        "spawn_time": 33.0,
        "label": "WAVE 3",
        "threats": [
            {"angle_deg":  30, "speed_mps": 14, "distance_m": 500},
            {"angle_deg": 160, "speed_mps": 14, "distance_m": 500},
            {"angle_deg": 290, "speed_mps": 14, "distance_m": 500},
        ],
    },
    {
        "spawn_time": 48.0,
        "label": "WAVE 4",
        "threats": [
            {"angle_deg":  10, "speed_mps": 16, "distance_m": 500},
            {"angle_deg": 130, "speed_mps": 16, "distance_m": 500},
            {"angle_deg": 250, "speed_mps": 16, "distance_m": 500},
        ],
    },
]

TOTAL_THREATS = sum(len(w["threats"]) for w in WAVE_SCHEDULE)

# ─── BLE GLOBALS ─────────────────────────────────────────────────────────────

BLE_ADDRESS   = None
ble_client    = None
ble_loop_ref  = None
ble_connected = False
ble_status    = "scanning"   # "scanning" | "connected" | "not found" | "disconnected"

BLE_RX_UUID = "62c3cf89-247b-4c0f-a70d-651080844608"
BLE_TX_UUID = "62c3cf89-247b-4c0f-a70d-651080844609"

latest_heading       = 0.0
heading_lock         = threading.Lock()
last_printed_heading = None

# ─── GAME STATE ──────────────────────────────────────────────────────────────

STATE_INTRO   = "intro"
STATE_PLAYING = "playing"
STATE_END     = "end"

state             = STATE_INTRO
game_time         = 0.0
threats           = []
animations        = []
screen_flash      = None
next_threat_id    = 0
waves_spawned     = 0
current_wave_num  = 0
misses            = 0
neutralized_count = 0
wave_notification = None
next_wave_timer   = None     # counts down after a wave clears before spawning the next
user_heading_deg  = 0.0

# ─── PYGAME INIT ─────────────────────────────────────────────────────────────

pygame.init()
screen_surf = pygame.display.set_mode((WIDTH, HEIGHT))
pygame.display.set_caption("Threat Simulation")
clock = pygame.time.Clock()

font_xl    = pygame.font.SysFont(None, 80)
font_large = pygame.font.SysFont(None, 56)
font_med   = pygame.font.SysFont(None, 36)
font_small = pygame.font.SysFont(None, 24)

# ─── GEOMETRY ────────────────────────────────────────────────────────────────

def bearing_to_screen(bearing_deg, distance_px):
    rad = math.radians(bearing_deg)
    return (CENTER[0] + distance_px * math.sin(rad),
            CENTER[1] - distance_px * math.cos(rad))

def get_threat_relative_angle(threat, heading_deg):
    dx = threat["x"] - CENTER[0]
    dy = CENTER[1]   - threat["y"]
    return (math.degrees(math.atan2(dx, dy)) - heading_deg) % 360

def get_threat_sector(threat, heading_deg):
    angle = get_threat_relative_angle(threat, heading_deg)
    return int(((angle + SECTOR_SIZE / 2) % 360) // SECTOR_SIZE)

def screen_to_global(x, y):
    return x - CENTER[0], CENTER[1] - y

# ─── BLE ─────────────────────────────────────────────────────────────────────

def quaternion_to_yaw_deg(w, x, y, z):
    siny_cosp = 2.0 * (w * z + x * y)
    cosy_cosp = 1.0 - 2.0 * (y * y + z * z)
    return math.degrees(math.atan2(siny_cosp, cosy_cosp))

def handle_ble_data(sender, data):
    global latest_heading, last_printed_heading
    try:
        values = [float(v) for v in data.decode().strip().split(",")]
        if len(values) != 4:
            return
        w, x, y, z = values
        yaw = -quaternion_to_yaw_deg(w, x, y, z)
        if last_printed_heading is None or abs(yaw - last_printed_heading) > 5:
            print(f"Heading: {yaw:.1f}°")
            last_printed_heading = yaw
        with heading_lock:
            latest_heading = yaw
    except Exception as e:
        print("BAD IMU:", e)

def send_ble_message(msg):
    if ble_loop_ref is None:
        return
    asyncio.run_coroutine_threadsafe(_ble_write(msg), ble_loop_ref)

async def _ble_write(msg):
    if ble_client is None:
        return
    try:
        await ble_client.write_gatt_char(BLE_TX_UUID, msg.encode())
    except Exception as e:
        print("BLE SEND FAILED:", e)

async def ble_loop():
    global BLE_ADDRESS, ble_client, ble_connected, ble_status
    print("Scanning for Argon...")
    devices = await BleakScanner.discover(timeout=10.0)
    for d in devices:
        print(f"  {d.name} | {d.address}")
        if d.name and "Argon" in d.name:
            BLE_ADDRESS = d.address
            break
    if BLE_ADDRESS is None:
        print("Argon not found.")
        ble_status = "not found"
        return
    print(f"Connecting to {BLE_ADDRESS}…")
    async with BleakClient(BLE_ADDRESS) as client:
        ble_client    = client
        ble_connected = True
        ble_status    = "connected"
        print("BLE connected.")
        await client.start_notify(BLE_RX_UUID, handle_ble_data)
        while client.is_connected:
            await asyncio.sleep(0.1)
        ble_connected = False
        ble_status    = "disconnected"
        print("BLE disconnected.")
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

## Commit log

2026-05-14 initial commit including IMU processing and heading management initial code
2026-05-14 Add GUI for threat visualization and motor control
    This script implements a simple GUI for visualizing the user's heading and a threat location, allowing interaction through mouse clicks and keyboard inputs.
2026-05-14 Add GUI for threat visualization and motor control
    This script implements a simple GUI for visualizing the user's heading and a threat location, allowing interaction via mouse and keyboard.
2026-05-20 multi-threat with variable force gui with BLE scanning and connection
    Updated comments for clarity, added Bluetooth support, and improved thread safety.
2026-05-20 listens to BLE capable device if MAC and ID are already known
2026-05-20 Add bleakScanner to scan for Particle Argon devices
2026-05-20 added drag and drop feature for existing threats
    This script implements a GUI for visualizing user heading and threat locations, allowing interaction through mouse and keyboard inputs. It supports multiple threats and sends motor commands based on 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
2026-05-20 adding threatmanager, some structural changes to belt controller
2026-05-20 integrating BLE functionality into belt_controller, adding an RX UUID to gui python scripts
2026-05-20 Major rework of controller test
    [HapticBelt.cpp, ThreatTracker.cpp, bleakListener.py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]
2026-05-20 adding RVC lib with Particle for Arduino replacement
2026-05-22 Add threat visualization and BLE communication
    This file implements a threat visualization system using Pygame and BLE communication. It allows users to create, drag, and remove threats, while transmitting threat data to a connected device.
2026-05-22 BeltIMU class to handle IMU
2026-05-24 refactoring belt_controller.ino into controllerTest class structure
2026-05-24 fixing rebase merge mistake
    [HapticBelt.cpp]
2026-05-24 fixing some compile errors
    [HapticBelt.cpp, ThreatTracker.cpp]
2026-05-26 fixing beltIMU reset
2026-05-26 updated gui with sector wheel for motor/threat visualization
2026-05-26 best version of the game simulation currently! fixed some minor bugs in brody's
    [gui_ashlynn_sim.py]
2026-05-28 Add brody_sim_main.py — merged Ashlynn logic with Brody UI
    Combines Ashlynn's spiral threat system and wave schedule with
    the improved forward-cone visualization, lock-on decay, and
    animated feedback from the Brody simulation scripts.
2026-05-28 fixed yaw backwardsness
2026-05-28 Tune brody_sim_main wave schedule to easy→moderate difficulty
    Reduce threat counts (max 3 per wave), slow speeds (10→16 m/s),
    widen wave gaps (15s), and lower spiral radial speed to match.
2026-05-28 Remove yaw negation in gui_update_on_event.py
2026-05-28 Restore yaw negation in gui_update_on_event.py
2026-05-28 Switch brody_sim_main to clearance-based wave spawning
    Each wave now only spawns after all threats from the previous wave
    are cleared, with a 3-second countdown between waves. Max 3 threats
    on screen at any time.
    [brody_sim_main.py]
2026-05-28 Push session updates to brody simulation and test scripts
    - Forward cone replaces full sector wheel
    - Lock-on decay (2x drain) instead of full reset
    - Offset/crossing/diagonal trajectory system
    - Amber color for diagonal threats
    - Range-exit detection for diagonal threats
    [update_on_event_brody_simulation.py, update_on_event_brody_simulation_TEST.py]
2026-05-28 Fix yaw sign in HapticBelt to match compass convention
    targetAzimuth uses atan2(x,y) which is clockwise-positive (compass).
    The raw quaternion yaw is counterclockwise-positive (standard math).
    Negating yaw makes both conventions match — same fix already applied
    on the Python side with -quaternion_to_yaw_deg().
    [HapticBelt.cpp]
2026-05-28 edits to yaw
2026-05-28 Fixed motor indices and sign errors
    [HapticBelt.cpp]
2026-06-03 README updates, adding STLs, and reorg
    [group14-2026-base-argon.stl, group14-2026-base-driver.stl, group14-2026-base-no-driver.stl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]
